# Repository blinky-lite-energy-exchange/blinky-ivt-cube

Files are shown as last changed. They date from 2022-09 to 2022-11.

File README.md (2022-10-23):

# Blinky IVT Cube
The Blinky-IVT cube controls an infrared diode to send pulses to an IVT heat pump. The pulse sequence is defined in the IVT.h file in the cubeCode folder. The pulse sequence was modified from [ToniA/arduino-heatpumpir](https://github.com/ToniA/arduino-heatpumpir). The [ToniA/arduino-heatpumpir](https://github.com/ToniA/arduino-heatpumpir) project contains pulse sequences for 29 different models of heat pumps so it possible to easily extend the Blinky IVT cube to many different models of heat pumps. The The microcontroller is a [Raspberry Pi Pico W](https://www.raspberrypi.com/products/raspberry-pi-pico/) that connects wirelessly to soft Blinky-Lite tray the resides on a Blinky-Lite box.

The Blinky IVT Cube sends and receives data from the [Blinky IVT tray](https://github.com/blinky-lite-energy-exchange/blinky-ivt-tray).

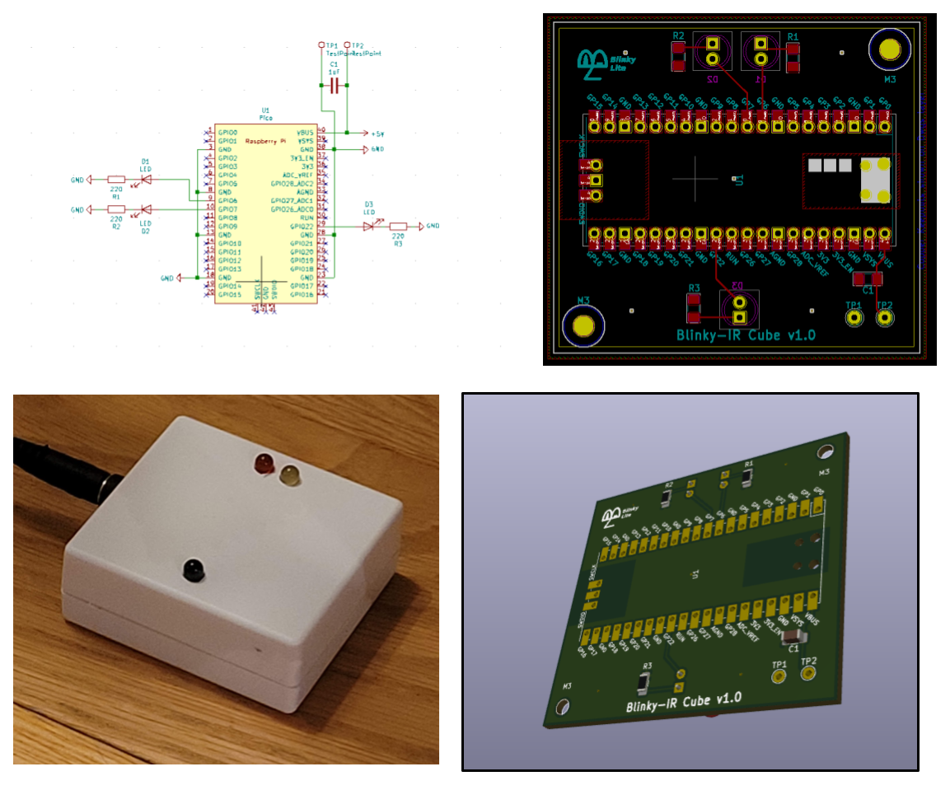
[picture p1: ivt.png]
<br>

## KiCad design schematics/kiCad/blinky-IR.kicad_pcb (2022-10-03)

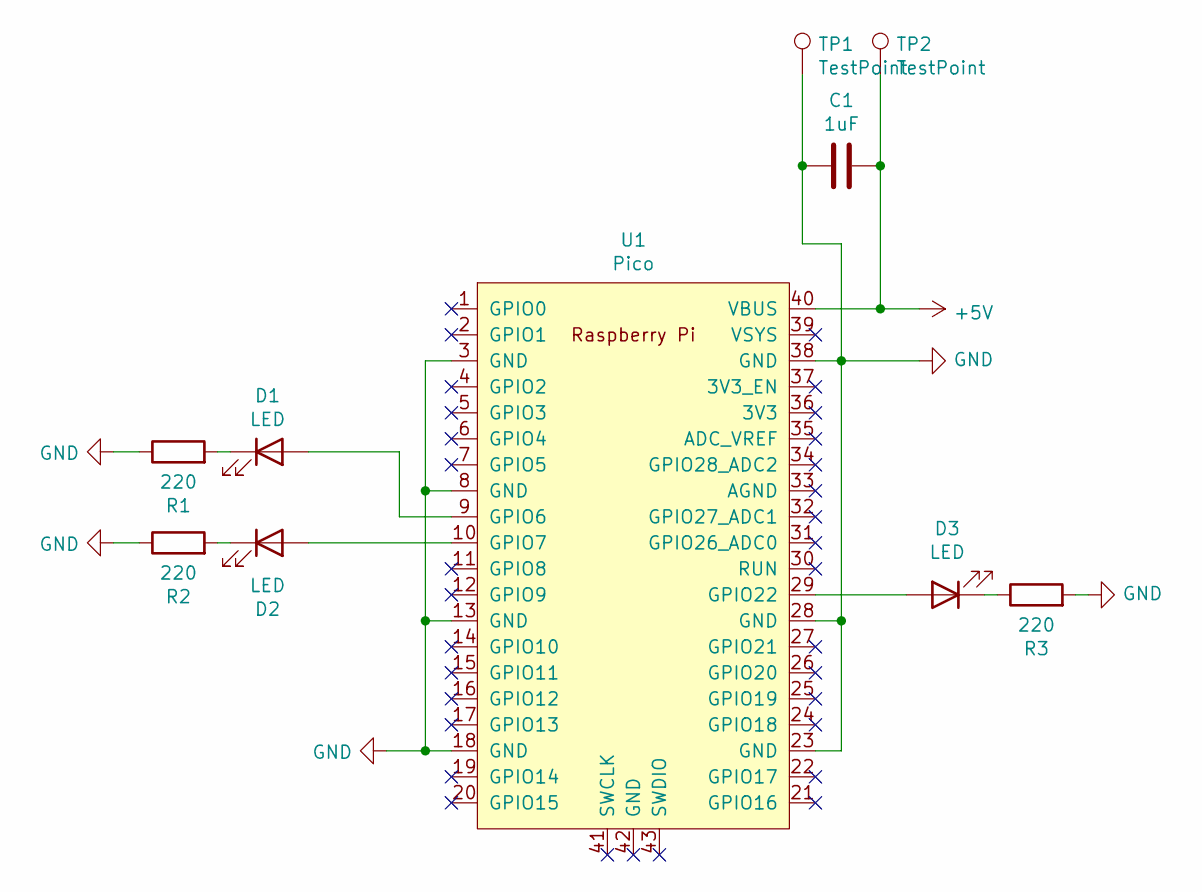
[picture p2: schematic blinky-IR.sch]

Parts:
C1: 1uF; C_1206_3216Metric_Pad1.42x1.75mm_HandSolder
D1, D2, D3: LED; LED_D5.0mm
R1, R2, R3: 220; R_1206_3216Metric_Pad1.42x1.75mm_HandSolder
TP1, TP2: TestPoint; TestPoint_THTPad_D2.0mm_Drill1.0mm
U1: Pico; RPi_Pico_SMD_TH

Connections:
+5V: C1.1, TP2.1, U1.40 (VBUS)
GND: C1.2, R1.1, R2.1, R3.2, TP1.1, U1.3 (GND), U1.8 (GND), U1.13 (GND), U1.18 (GND), U1.23 (GND), U1.28 (GND), U1.38 (GND)
unnamed: D1.1 (K), R1.2
unnamed: D1.2 (A), U1.9 (GPIO6)
unnamed: D2.1 (K), R2.2
unnamed: D2.2 (A), U1.10 (GPIO7)
unnamed: D3.1 (K), R3.1
unnamed: D3.2 (A), U1.29 (GPIO22)

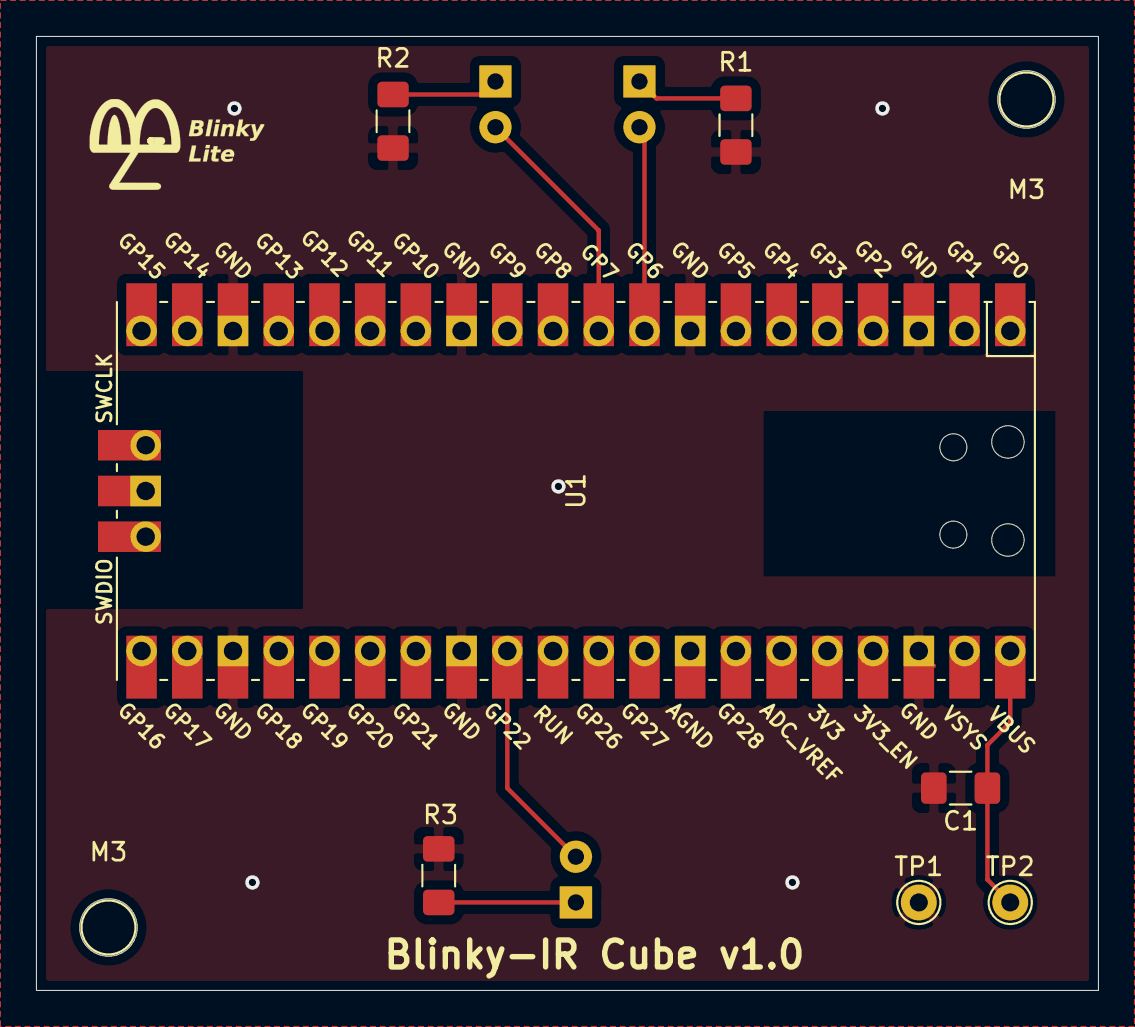
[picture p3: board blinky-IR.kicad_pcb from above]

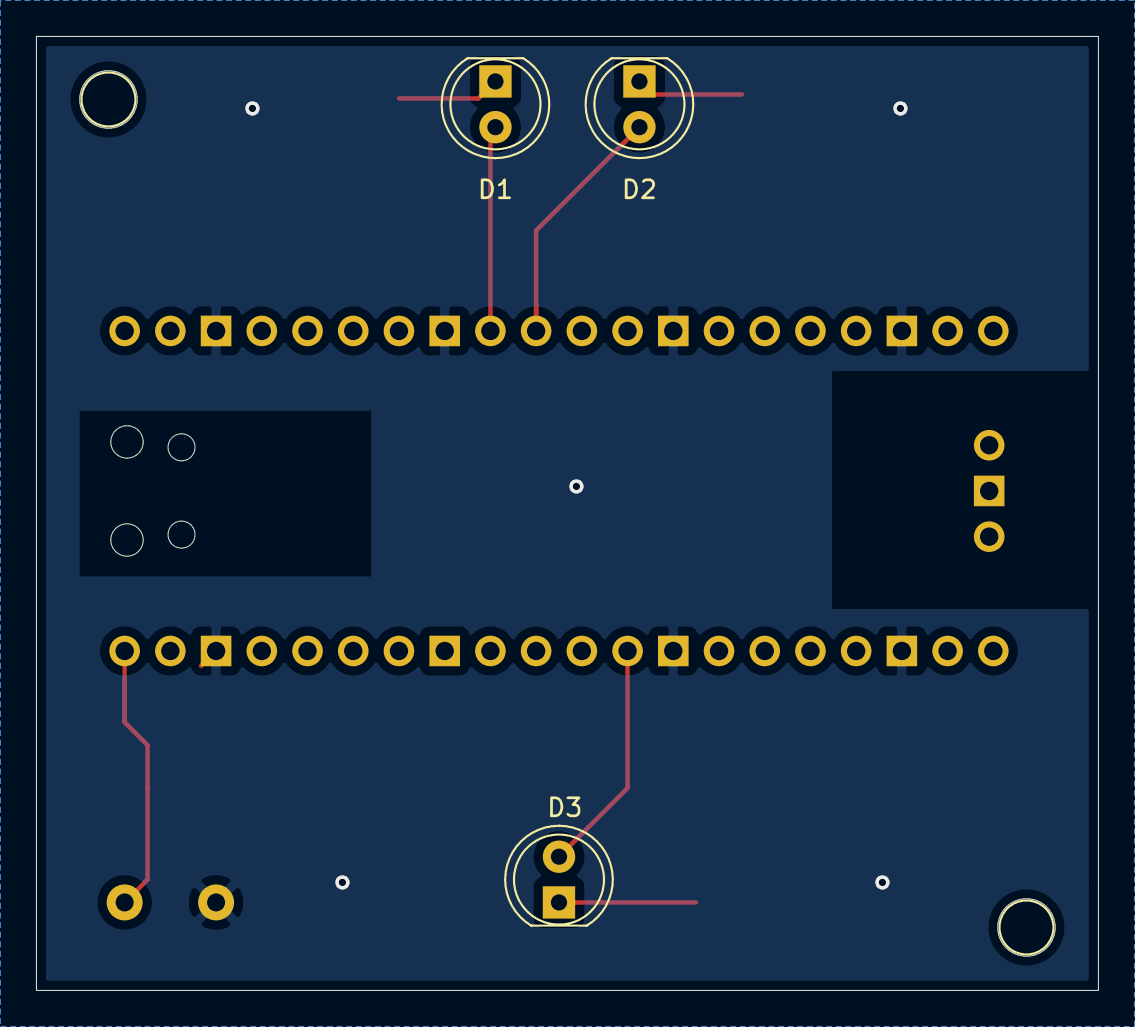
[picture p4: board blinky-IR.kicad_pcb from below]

Board: 2 copper layers, 59.0 x 53.0 mm, 12 parts (3 on the bottom side), 8 nets.

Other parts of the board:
M3, M3#2: MountingHole_3.2mm_M3

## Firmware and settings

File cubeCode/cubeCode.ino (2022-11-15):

#include "BlinkyMqttCube.h"
#include "IVT.h"

struct
{
  int16_t state;
  int16_t watchdog;
  int16_t chipTemp;
  int16_t power;
  int16_t mode;
  int16_t fan;
  int16_t temperature;
  int16_t hour;
  int16_t min;
} cubeData;

void subscribeCallback(uint8_t address, int16_t value)
{
  if (address == 8) setHeatPump();
}

int cubeAlivePin = 6;
IVTHeatPump ivtHeatPump = IVTHeatPump();


void setup() 
{
  pinMode(cubeAlivePin, OUTPUT);
  analogWrite(cubeAlivePin, 20);
//  Serial.begin(115200);
  delay(1000);
  ivtHeatPump.init(22);
  BlinkyMqttCube.setChattyCathy(false);
  BlinkyMqttCube.init(2000,true, 7, 50, -1, (int16_t*)& cubeData,  sizeof(cubeData), subscribeCallback);

  cubeData.power = POWER_OFF;
  cubeData.mode = MODE_HEAT;
  cubeData.fan = FAN_AUTO;
  cubeData.temperature = 18;
  cubeData.hour = 1;
  cubeData.min = 1;
  
  setHeatPump();
}

void loop() 
{
  BlinkyMqttCube.loop();
  cubeData.chipTemp = (int16_t) ((analogReadTemp() - 4.5) * 100.0);
}
void setHeatPump()
{
  if (cubeData.state == 0)
  {
    analogWrite(cubeAlivePin, 0);
    delay(500);
//    Serial.println("Setting Heat Pump");
    ivtHeatPump.setIVTMode(cubeData.power, cubeData.mode, cubeData.fan, cubeData.temperature, cubeData.hour, cubeData.min);
    delay(500);
    int ledBright = 20 + 7 * (cubeData.temperature - 18);
    if (ledBright < 10) ledBright = 10;
    if (cubeData.power == POWER_ON) analogWrite(cubeAlivePin, ledBright);
  }
}

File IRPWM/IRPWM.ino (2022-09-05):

#include "IVT.h"
IVTHeatPump ivtHeatPump = IVTHeatPump();

void setup() 
{
  ivtHeatPump.init(13);
  pinMode(2, OUTPUT);
  digitalWrite(2, HIGH);
  delay(1000);
  digitalWrite(2, LOW);
  delay(10000);
  digitalWrite(2, HIGH);
  ivtHeatPump.setIVTMode(POWER_ON, MODE_HEAT, FAN_AUTO, 23, 14, 8);
  delay(1000);
  digitalWrite(2, LOW);
  delay(20000);
  digitalWrite(2, HIGH);
  ivtHeatPump.setIVTMode(POWER_OFF, MODE_HEAT, FAN_AUTO, 23, 14, 8);
  delay(1000);
  digitalWrite(2, LOW);
}

void loop() 
{
}

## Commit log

2022-10-03 added picoW to schematic
    [blinky-IR.kicad_pcb, blinky-IR.sch, blinky-lite-basic.kicad_pcb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]
2022-11-12 new class structure for pico
2022-11-17 fixed mqtt mem problem
    [BlinkyMqttCube.h]
